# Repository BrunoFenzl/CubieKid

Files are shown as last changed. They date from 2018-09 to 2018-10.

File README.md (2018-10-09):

# CubieKid 

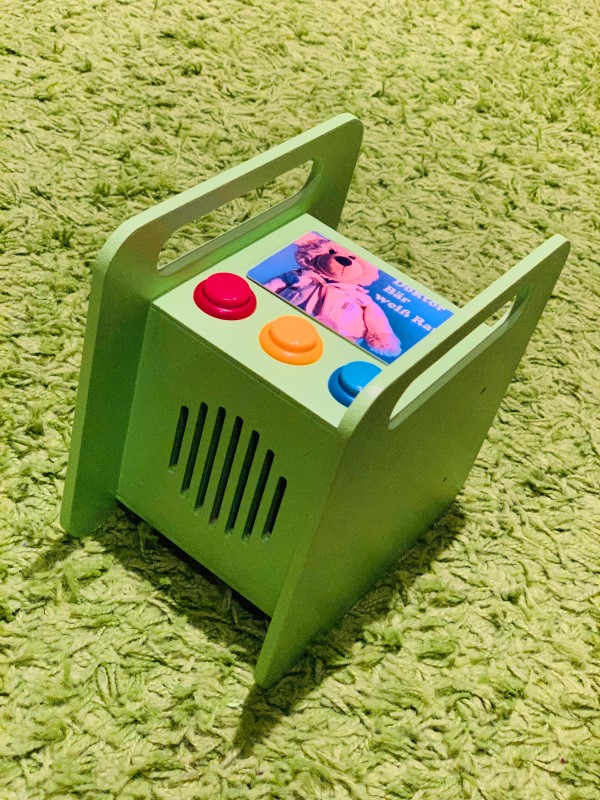
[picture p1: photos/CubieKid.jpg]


## A cute MP3 player project - made-to-measure (small) children's needs.

When I learned about [Thorsten's TonUINO project](https://www.voss.earth/tonuino/) I decided to create a compatible housing which fits the needs of (small)kids and parents. The result is CubieKid. It is still an ongoing process as I get improvement suggestions and comments to make it even better.

There are no sharp corners, no external screws or loose parts. The speaker is scoop-proof covered. For serviceing (audio-files and battery-change) the access panel can be removed with a designated tool only. 

The whole player is powered by batteries, accu pack or USB-power-bank. So there is no need for external cables and power supplies. This all makes CubieKid the ideal all-day companion.

### Housing

This housing can be made from medium density fibreboard with a thickness of 3mm (sorry folks this is a german design - so everything is in metric dimensions).

I'm using a homemade CNC-mill ([Make: MaXYposi](https://www.heise.de/make/artikel/MaXYposi-Projektseite-zum-universellen-XY-Portalroboter-von-Make-3676050.html)) which works well. But you can use a Laser Cutting Device as well.

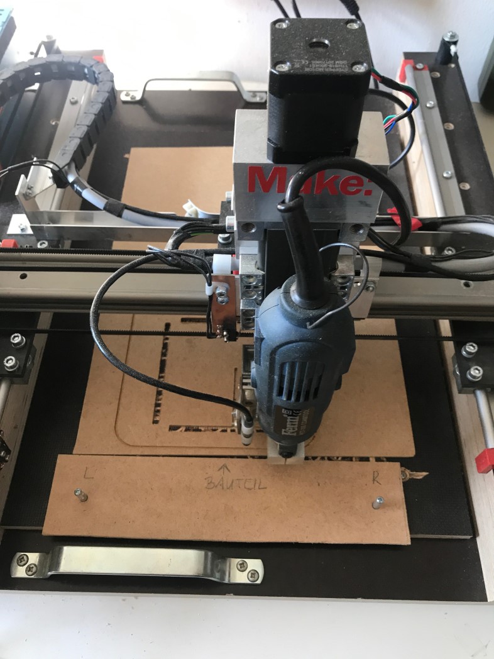
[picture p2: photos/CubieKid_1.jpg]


### Electronics

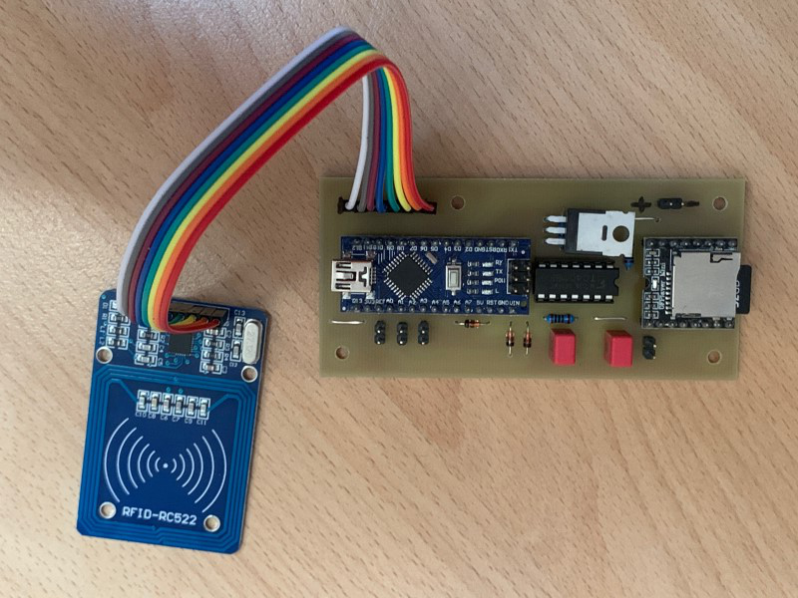
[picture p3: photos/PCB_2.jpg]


The newest upgrade is an optimized circuit and the associated single-sided pcb. So the reproduction is easy and inexpensive.

Highlights:

- Intended to be used with batteries, accu packs and USB-powerbanks

- Power-On with one of the three buttons

- Auto-standby-function saves battery live by reducing current down to less than 0,25 mA

- Battery voltage monitoring function with audio alert and shut-down

## Construction Manual

Please follow the instructions step by step to build a good looking and stable box.

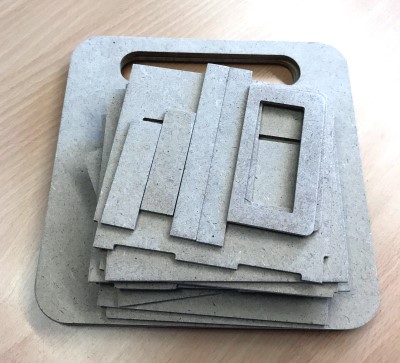
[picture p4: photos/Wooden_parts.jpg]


#### Wooden parts

Cut out all parts. You need medium density fibreboard with a thickness of 3mm. Here's a survey with all wooden parts you need:

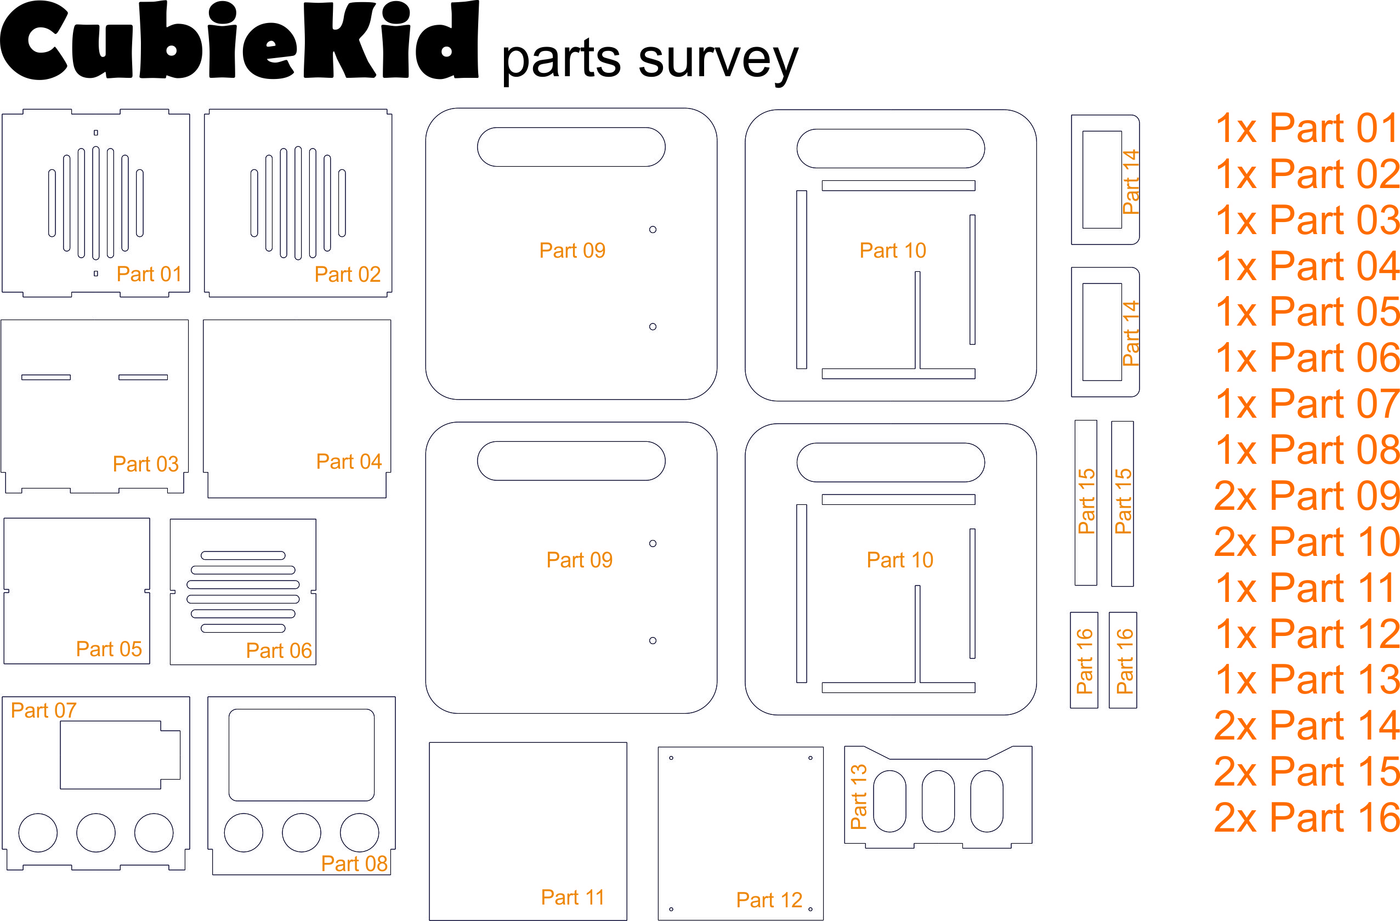
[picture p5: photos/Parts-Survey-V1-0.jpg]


#### Additional material

You will need some more things to build CubieKid:

- PVA glue (fast-drying type recommended)
- 1 x 32mm foldback clip
- 4 x Small socket screws for wood, length: 5-6mm
- 2 x Metric screw M4 x 20mm
- 2 x M4 nut

#### Front-, Top-, Bottom and Side panels

Glue the both front panels together. Do the same likewise with the top- and bottom panels. Make sure that the engraving of the card area on upper top panel is visible.

Take two different side panels and glue them together. Continue with the remaining side panels but make sure they’re glued together mirror-inverted. So you’ll get a right and a left side for the box.

The speaker will be glued (hot-glue) on a second speaker grid which makes the speaker scoop-proof.

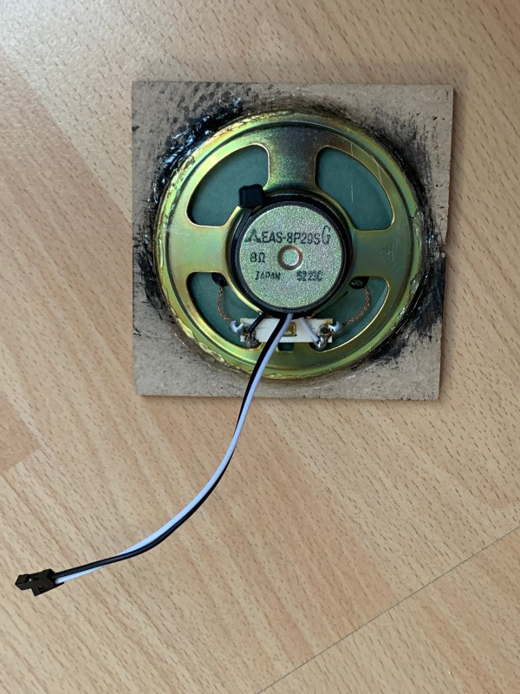
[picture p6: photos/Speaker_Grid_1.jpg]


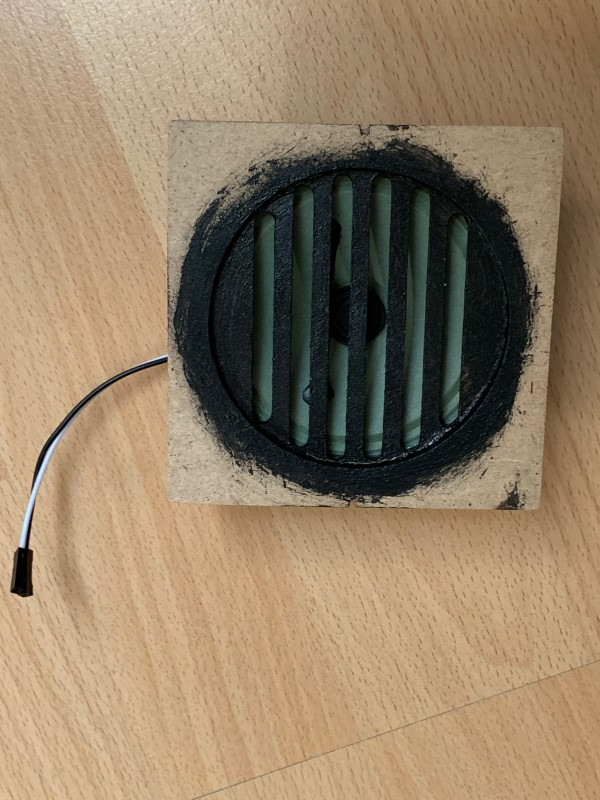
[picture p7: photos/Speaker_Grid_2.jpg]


 I am using a recycled speaker (out of an old amateur radio) with 7 cm diameter and 1 Watt power. The speaker grid has two adjusting-notches which should fit the corresponding notches on the inner front panel.

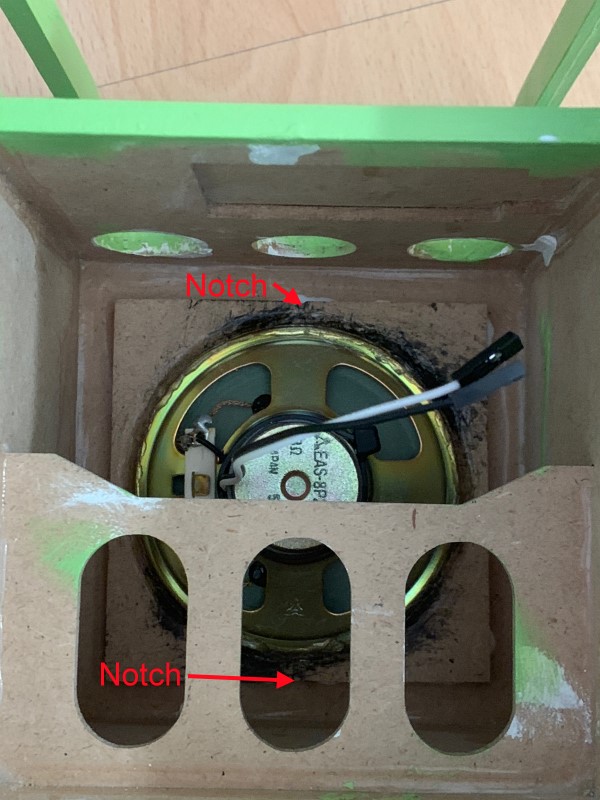
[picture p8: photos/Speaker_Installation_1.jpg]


#### Back panel (Service Access)

Now you can start to assemble the back-cover with the locking function. Take the panel (that’s the one without any drill holes.) and put it into its later position at the box. 

Glue the two long rectangular parts to the inner side of the back panel. They will keep the back panel in place, so they should be quite close to the upper / lower corner. Do NOT apply glue to the side facing the upper/lower panel – the back panel must be removable. Every box is a little bit different so it is the best to fix thr rear panel at the half-finished box (like at the photo) then glue in the rectangular parts and push them in the direction of the yellow arrows.

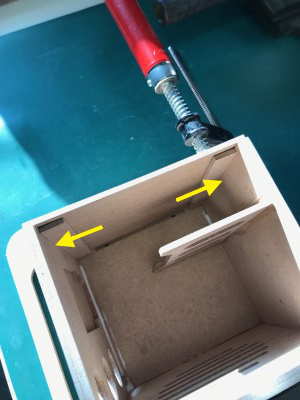
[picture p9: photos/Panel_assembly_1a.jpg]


Now we need the two D-shaped sliders and the two smaller rectangular pieces. To make sure the slider’s function they probably need to be sandpapered to somewhat less than 3mm thickness.

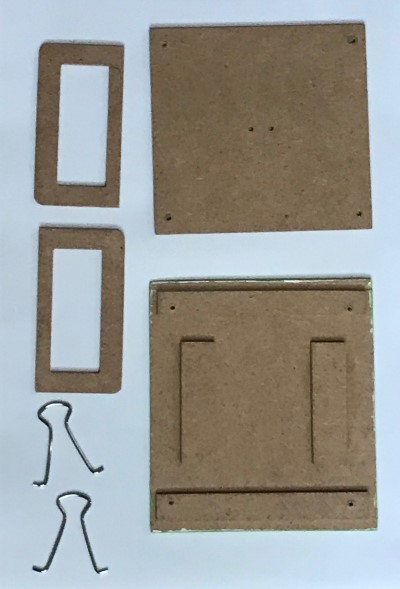
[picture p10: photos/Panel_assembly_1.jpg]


Put the siders on the inner side of the back panel – the rounded corners must face outside. Do NOT glue them. Put a small rectangular piece into each D-hole. Find a position where the slider is able to slide out about 4-5mm, then glue the rectangular piece to the back panel. The small rectangular pieces act as stoppers protecting the sliders from being pushed out too far.

Now we have a nice little two-sided sliding mechanism. To apply the mechanical force to keep the sliders in the outer position we will need a 32mm foldback-clip. 

Remove the handles of the foldback-clip and discard the black metal part. We’ll only need the handles. Insert the handles between the sliders -the open sides must face the center.

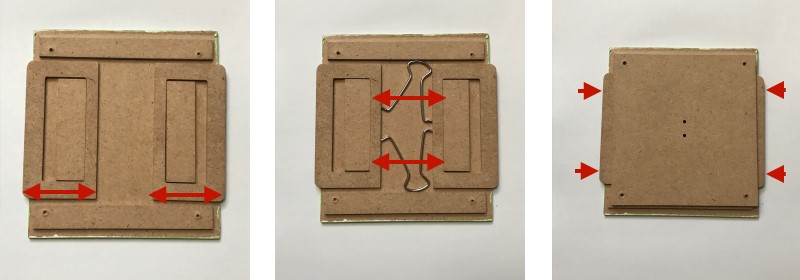
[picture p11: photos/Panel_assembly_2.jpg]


Now attach the inner panel (that one with four small holes) with small screws.

Your back panel is now ready to be snapped into position. But be aware: You’ll need to build a removal tool first to be able to remove the back panel again.

#### Opening Tool

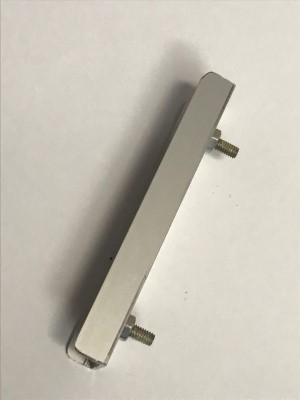
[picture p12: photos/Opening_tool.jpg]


To open the rear panel you will need an opening tool. Take a piece of wood or aluminium (length: about 9cm) and drill two 4mm holes (space center/center: 60mm). Insert a M4 screw* into each hole and fix it with a M4 nut. 

*:The screws need to be long enough to pust the slider out of the adjacent side panel.

Use: Push the opening tool into the holes on one side of the box. Now pull the rear panel away from the box at that side you attached the tool. It will work on both sides (some kind of redundancy thanks to the use of the same part on both sides).

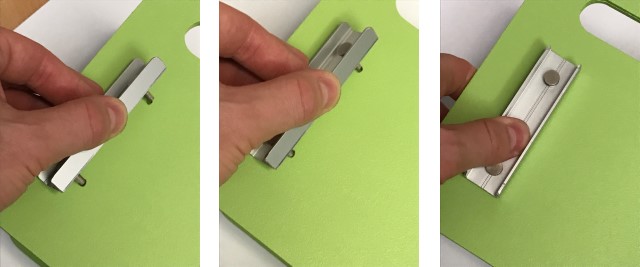
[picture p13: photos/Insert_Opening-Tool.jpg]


### Electronic Assembly



You will need:

- 1x 	pcb "CubieKid"
- 1x	Arduino Nano (clone)
- 1x	DFPlayer Mini Module
- 1x	RFID-RC522 Shield and compatible RFID-cards
- 1x	IC CD 4011 (DIL)
- 1x	SD Card (up to 32GB)
- 1x	Diode 1N4001
- 3x	Diode 1N4148
- 1x	FET IRF 4905
- 2x	Resistor 1k
- 1x	Resistor 100k
- 1x	Resistor 33k
- 2x	Capacitor 0,1uF (100nF), e.g. WIMA MKS2
- 1x	Speaker (7cm diameter, 8 Ohms, 1...3 Watts)
- 3x	24mm pushbuttons

and:

Connecting cables, pinheaders, battery holder(s), 5 cm silver wire (0,8mm diameter).

The finished pcb looks like this:

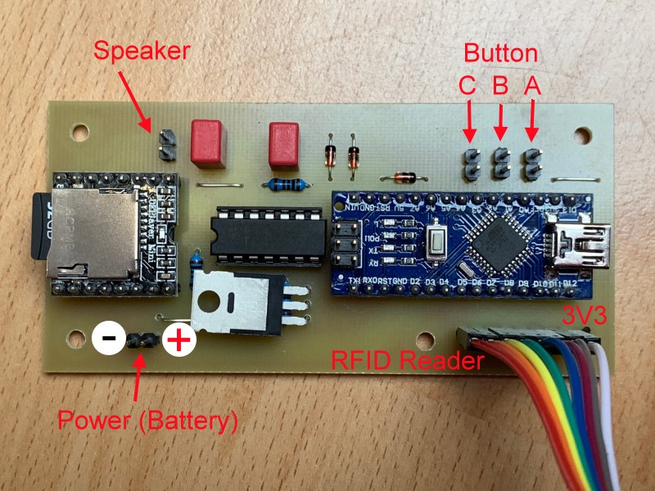
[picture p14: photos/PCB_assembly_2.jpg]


It is small enough to be fitted on the upper half of the rear panel. So the access to the Micro-SD Card and USB-Port are easy. Make sure the connecting wires are long enough to open the panel.

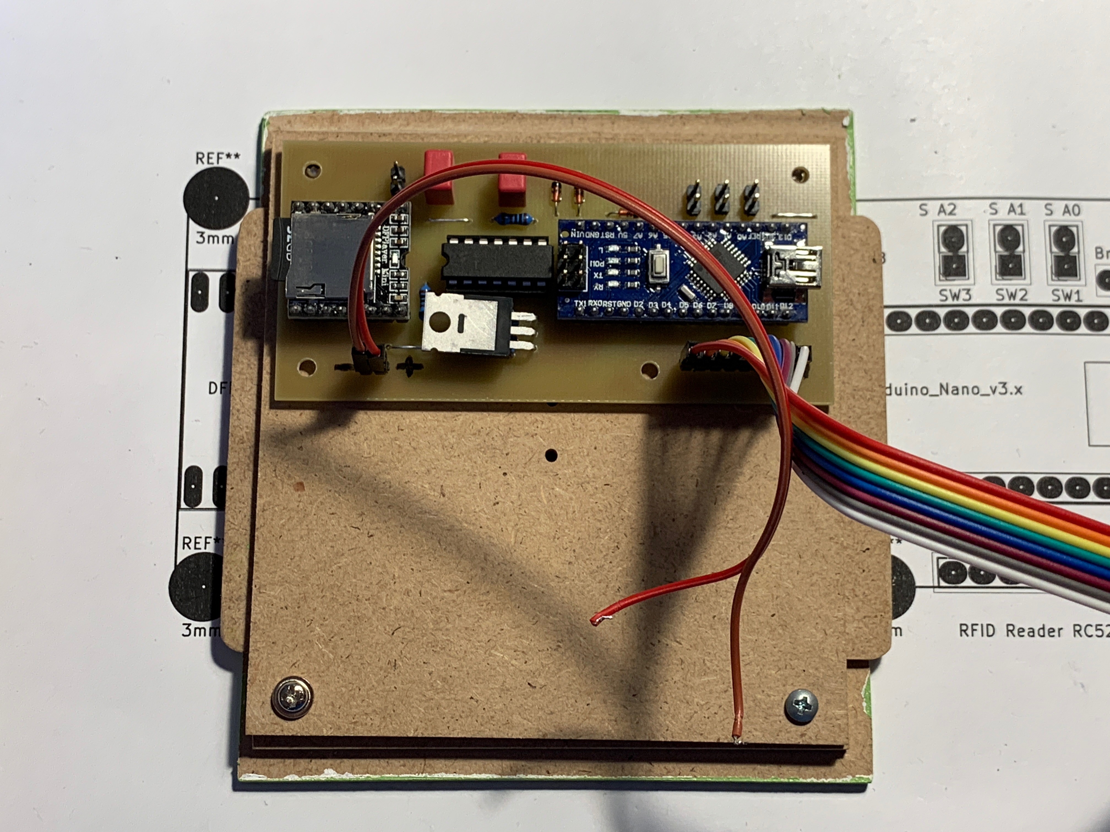
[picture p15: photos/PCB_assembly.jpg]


...to be continued.

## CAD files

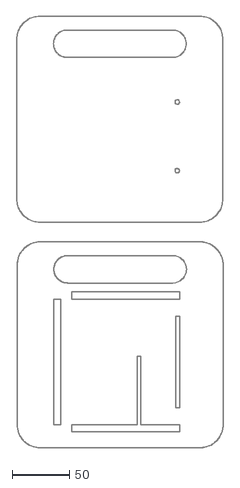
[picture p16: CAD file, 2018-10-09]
dxf-files/A3/parts-09-10.dxf
180.3 x 377.2

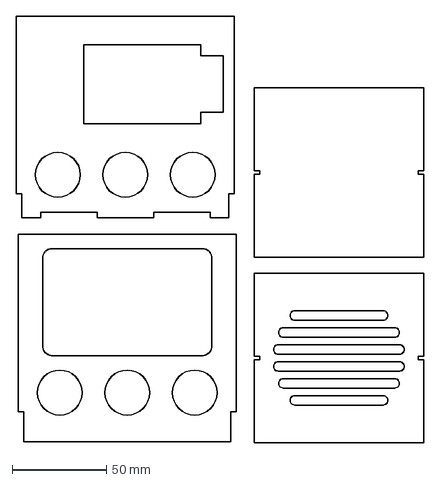
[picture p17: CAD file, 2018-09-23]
dxf-files/MaXYposi/Topside_and_Speaker_Grid.dxf
216.3 x 226.3 mm

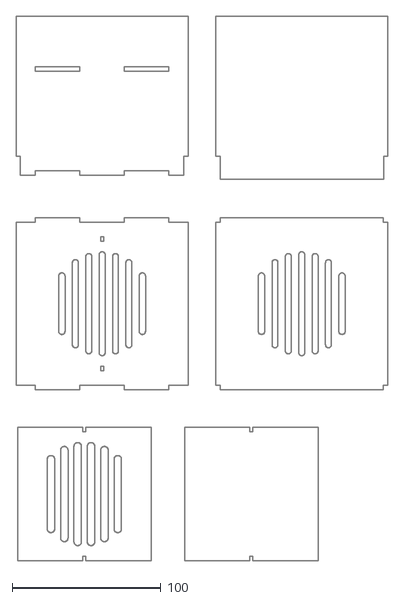
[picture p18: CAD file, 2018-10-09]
dxf-files/A3/parts-01-to-06.dxf
250.3 x 366.8

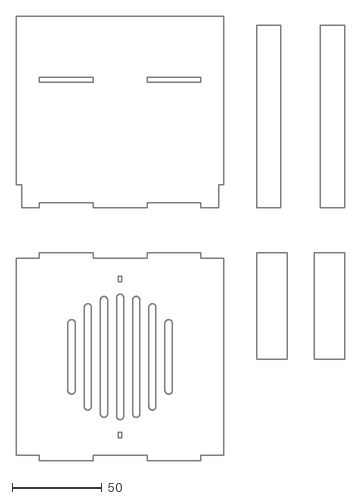
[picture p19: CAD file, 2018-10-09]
dxf-files/A4/parts-01-03-15-15-16-16.dxf
183.1 x 248.1

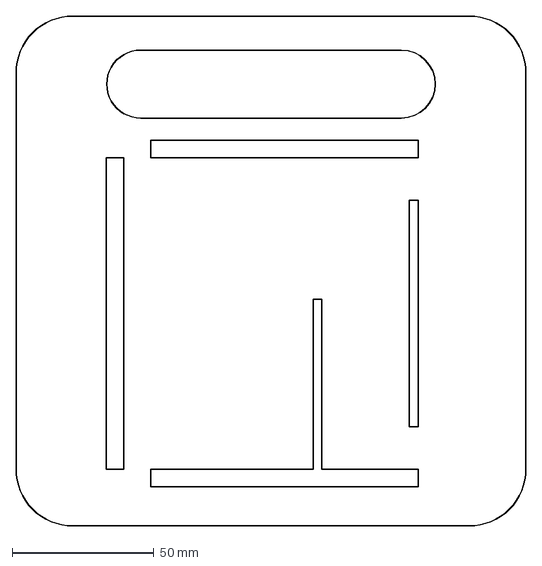
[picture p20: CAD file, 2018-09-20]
dxf-files/MaXYposi/Sidepanel_1.dxf
180.0 x 180.0 mm

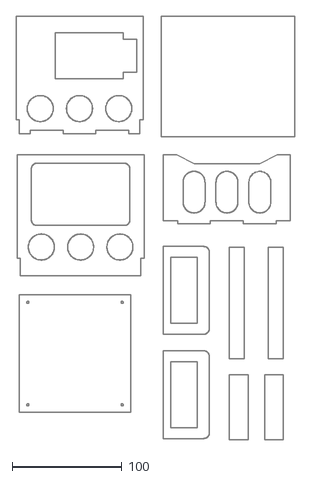
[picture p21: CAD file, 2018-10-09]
dxf-files/A3/parts-07-08-11-to-16.dxf
254.3 x 386.2

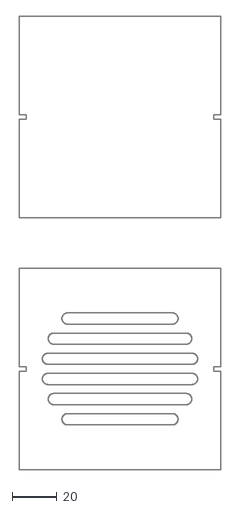
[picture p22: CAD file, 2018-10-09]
dxf-files/A4/parts-05-06.dxf
90.0 x 202.5

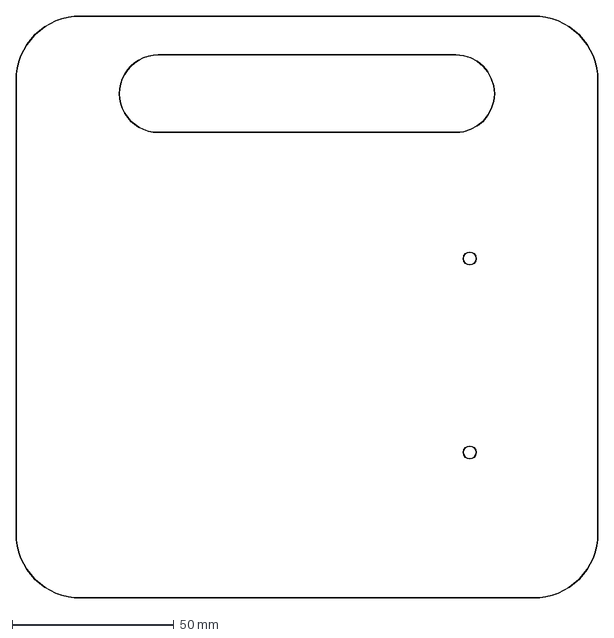
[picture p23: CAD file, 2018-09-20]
dxf-files/MaXYposi/Sidepanel_2.dxf
180.0 x 180.0 mm

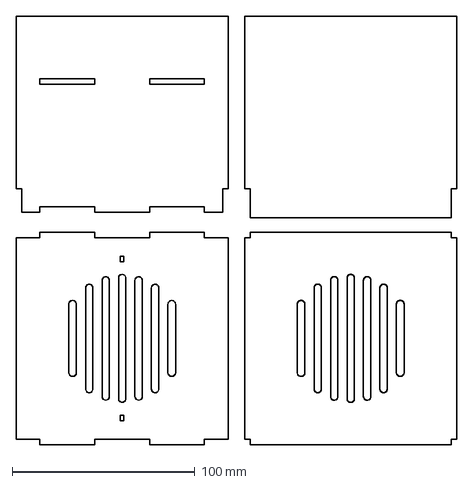
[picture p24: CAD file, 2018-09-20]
dxf-files/MaXYposi/Frontside_and_Bottom-Panel.dxf
240.8 x 234.0 mm

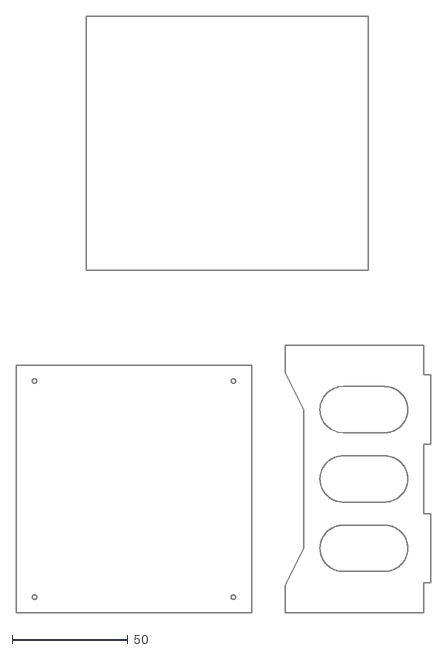
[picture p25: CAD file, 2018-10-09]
dxf-files/A4/parts-11-12-13.dxf
179.5 x 258.1

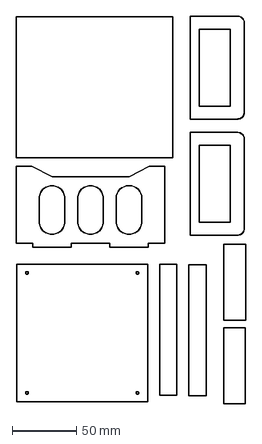
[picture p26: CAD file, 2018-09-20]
dxf-files/MaXYposi/Backpanel_w_Lock.dxf
178.8 x 301.8 mm

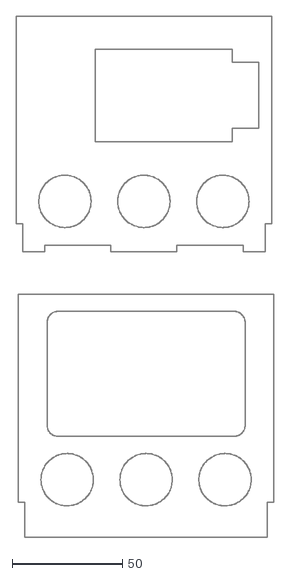
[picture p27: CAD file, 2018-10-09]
dxf-files/A4/parts-07-08.dxf
116.8 x 236.3

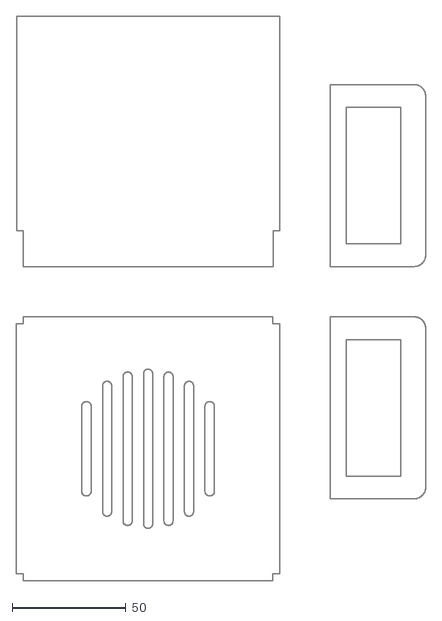
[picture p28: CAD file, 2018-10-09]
dxf-files/A4/parts-02-04-14-14.dxf
179.9 x 248.1

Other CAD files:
dxf-files/A4/parts-09.dxf
dxf-files/A4/parts-10.dxf

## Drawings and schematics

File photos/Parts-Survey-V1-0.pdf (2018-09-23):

## CubieKid parts survey

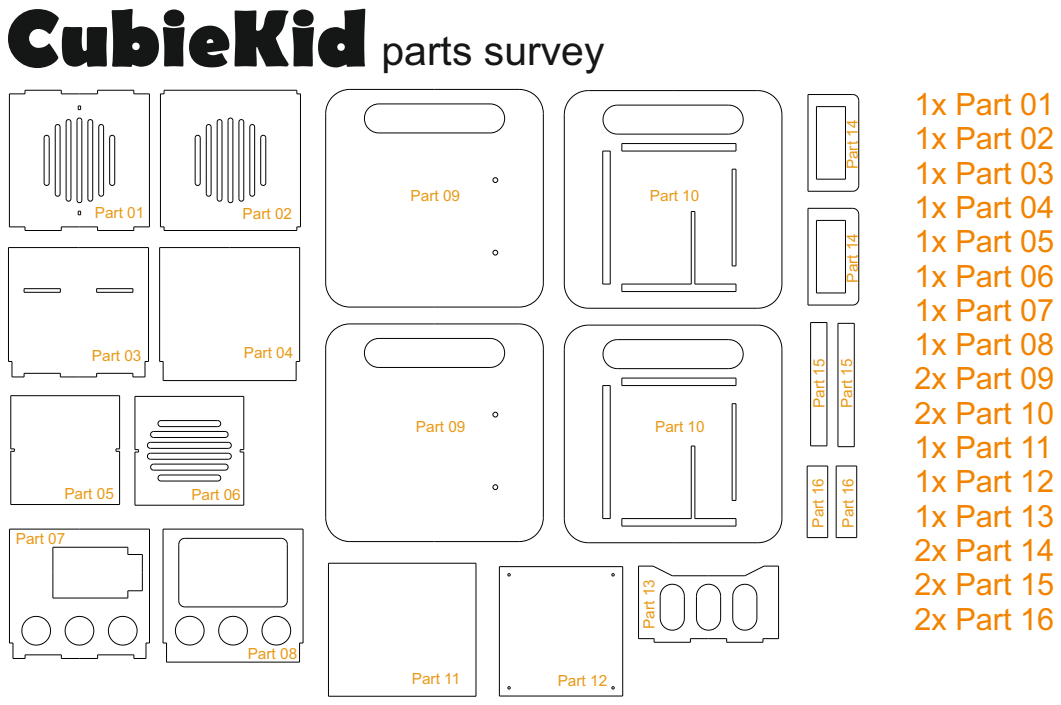
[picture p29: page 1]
Part 01; Part 02; Part 03; Part 04; Part 05; Part 06; Part 07; Part 08; Part 09; Part 10; Part 1; Part 12; Part 13; Part 14 Part 14; Part 15; Part 16; 1x Part 01 1x Part 02 1x Part 03 1x Part 04 1x Part 05 1x Part 06 1x Part 07 1x Part 08 2x Part 09 2x Part 10 1x Part 1; 1 1x Part 12 1x Part 13 2x Part 14 2x Part 15 2x Part 16

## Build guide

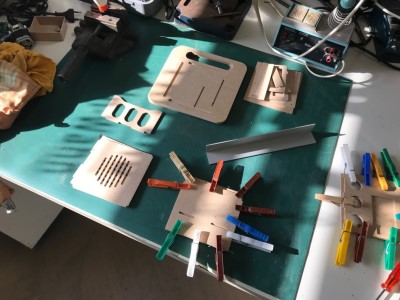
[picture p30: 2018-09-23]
photos/CubieKit_Assembly_2.jpg

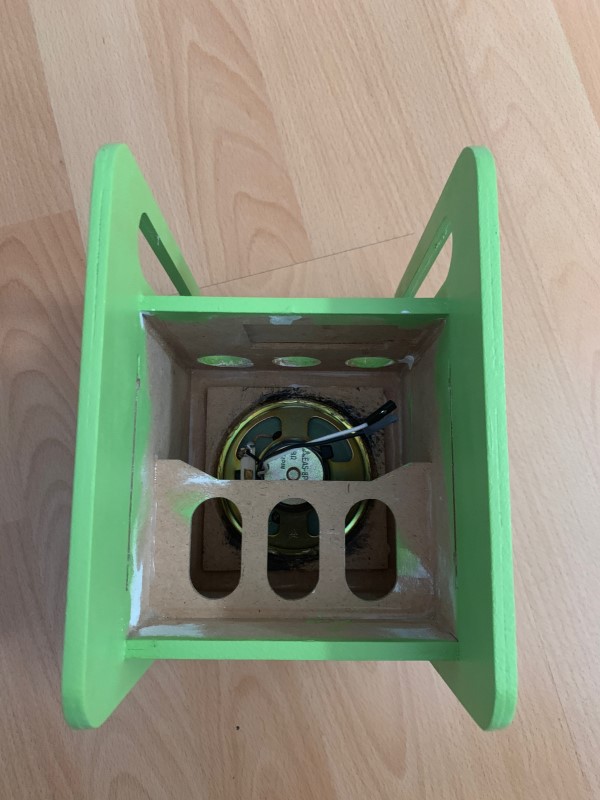
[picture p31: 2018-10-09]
photos/Speaker_Installation_2.jpg

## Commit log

2018-09-20 Added DXF files for cutting
    [Backpanel_w_Lock.dxf, Frontside_and_Bottom-Panel.dxf, Sidepanel_1.dxf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]
2018-09-23 Added Photos and Instruction
    [Topside_and_Speaker_Grid.dxf]
2018-10-05 Added new material size DIN A4
    [parts-01-03-15-15-16-16.dxf, parts-02-04-14-14.dxf, parts-05-06.dxf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]
2018-10-09 Moved dxf files batch for MaXYposi CNC in subfolder
    [Backpanel_w_Lock.dxf, Frontside_and_Bottom-Panel.dxf, Sidepanel_1.dxf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]
2018-10-09 Photos of assembly and new PCB
2018-10-09 Added pcb infos
2018-10-09 PCB details added
2018-10-09 Added new material size DIN A3
    [parts-01-to-06.dxf, parts-07-08-11-to-16.dxf, parts-09-10.dxf]

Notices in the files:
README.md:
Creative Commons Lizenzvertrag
